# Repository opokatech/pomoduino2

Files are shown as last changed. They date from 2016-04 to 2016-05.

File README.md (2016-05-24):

# Pomoduino2

This project is a simple [pomodoro] hardware timer using [arduino] uno with 16x2
lcd display, 2 buttons and a buzzer.

It keeps track of finished pomodoros (saves them to non-volatile memory) and
counts them up. The logic is described below.

A prototype with Arduino looks like this:

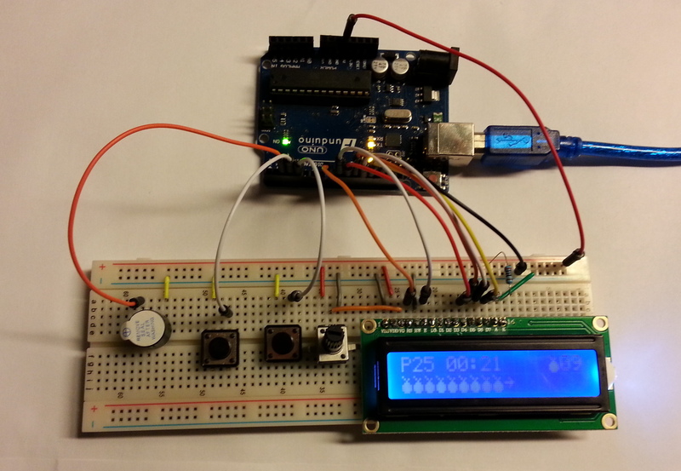
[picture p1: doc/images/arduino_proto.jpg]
pomoduino2 arduino proto Pomoduino2 prototype with arduino
.

... and using nano - like this:

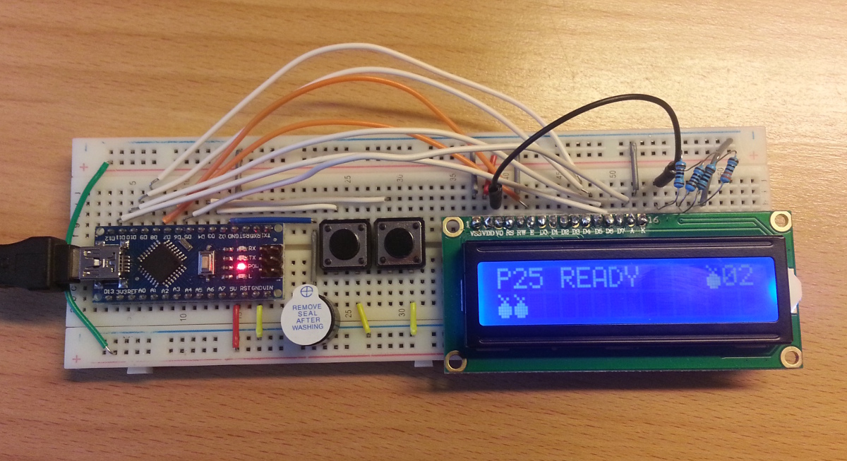
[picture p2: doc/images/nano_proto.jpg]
pomoduino2 nano proto Pomoduino2 prototype with nano
.

# Logic - description

There are 3 timers:
- 25 minutes (aka pomodoro),
- 5 minutes (aka short break),
- 15 minutes (aka long break)

Pressing (and releasing) button 1 (B1) cycles through them.

Pressing (and releasing) button 2 (B2) starts a timer.

When timer elapses it goes automatically to a next one, as described in
[pomodoro] method, i.e. 25 - 5 - 25 - 5 - 25 - 5 - 25 - 15 - 25 - 5 ...

Number of finished pomodoros is visible in the top right corner and also
visualized as a progress bar in the bottom line.

Pressing B2 while running pauses the state. Pressing (and releasing) again makes
it continue.

Holding B2 longer (3s) during pause cancels the timer - it goes back to `ready`
state.

Holding B2 longer (3s) in ready state clears the number of pomodoros done so
far.

The pomodoros are stored in eeprom and thus survive power off.

On a diagram it looks like so:

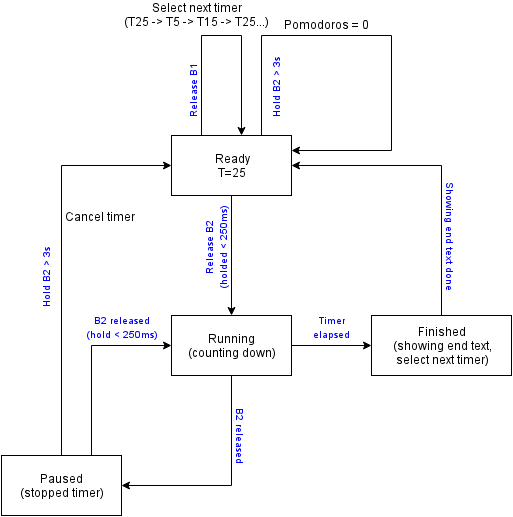
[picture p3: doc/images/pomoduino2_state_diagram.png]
state diagram of pomoduino2 timer State diagram
.

The drawing was made with [draw.io](https://www.draw.io/).

# Schematic

The components were connected as depicted below:

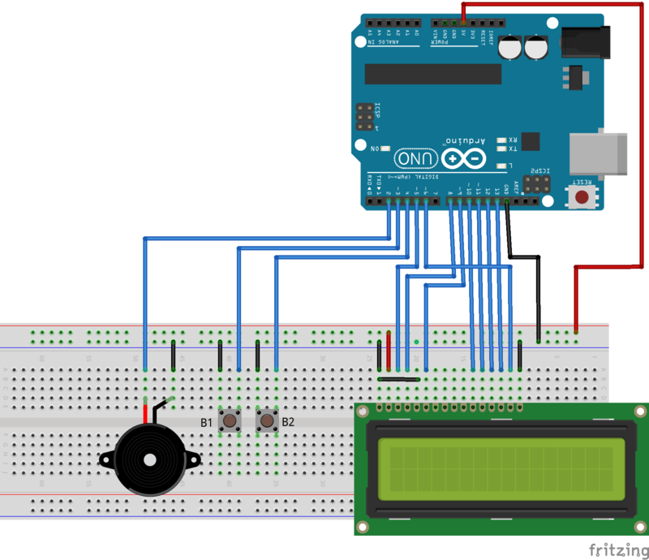
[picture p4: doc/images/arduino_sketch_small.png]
sketch of pomoduino2 timer Sketch diagram
.

# Building

## Hardware

- [arduino] - I used uno and nano328 but should work with others too. As you can
  see it just uses input from 2 buttons and several outputs (LCD, buzzer) so it
  could be adapted to any device having digital I/Os
- 16x2 LCD display - although the software is made so that the UI class, which
  now uses LCD, can be easily replaced by literally anything. As an example
  there is src-alternative/ui/serial/UI, which spits out something on Serial
  console depending on current state. Yet another example (included) is a
  variant using 5 LEDs as "user interface".
- 10k potentiometer (optional) - for controlling contrast. If you don't want
  that just use some resistor placed between V0 pin of the LCD and ground. For
  me 3.3k Ohm worked well, however using a capacitor (100uF) as you can see here:
  [here](/doc/images/nano_sketch_big.png) worked best (forming simple RC
  filter with D5 as PWM).

- 2 buttons
- buzzer - although, again, it can be replaced by any device controller by
  digital output, for example a LED.

## Software

### Quickstart

I'm using [debian] so I could do just this:
```sh
$ apt-get install arduino arduino-mk cmake g++
```

Then in the directory where this repository was cloned:
```sh
$ make lcd # to build a ready to use version
$ make upload # to upload compiled binary to the arduino
```

If you want to play a bit with it there are few more commands, like:

```sh
$ git submodules update --init # to fetch google tests/mock
$ make test # to compile and run tests

$ make lcd-debug # to build a debug version (see below)
$ make serial-debug # to build a debug version with UI_Serial instead of UI_Full
```

### Some explanations

To compile I used arduino-mk. I really recommend that as an alternative to the
official IDE - especially if you would like to:
- use your favourite text editor,
- be able to easily adjust compile options
- make automated builds and testing.

That code is very likely to work using the standard [arduino] IDE, provided that
the files are put in right directories. But I neither tested that nor plan to.

The `debug` target adds some extra debug messages which are spit out on serial
interface (with `picocom /dev/ttyUSB0` you can watch it) AND it changes times of pomodoro
periods from minutes to seconds which is very useful for testing.

For testing the code I used [google test] which also includes google mock. I
used both as submodules (they are in `/modules` directory). It matters of
course only if you need/want to run tests.

# License

[MIT](LICENSE)

----
Documentation was tested using [dillinger.io](http://dillinger.io/).

[//]: # (These are reference links used in the body of this note and get stripped out when the markdown processor does its job. There is no need to format nicely because it shouldn't be seen. Thanks SO - http://stackoverflow.com/questions/4823468/store-comments-in-markdown-syntax)

[arduino]: <https://www.arduino.cc/>
[debian]: <https://www.debian.org/>
[googletest]: <https://github.com/google/googletest>
[pomodoro]: <https://en.wikipedia.org/wiki/Pomodoro_Technique>

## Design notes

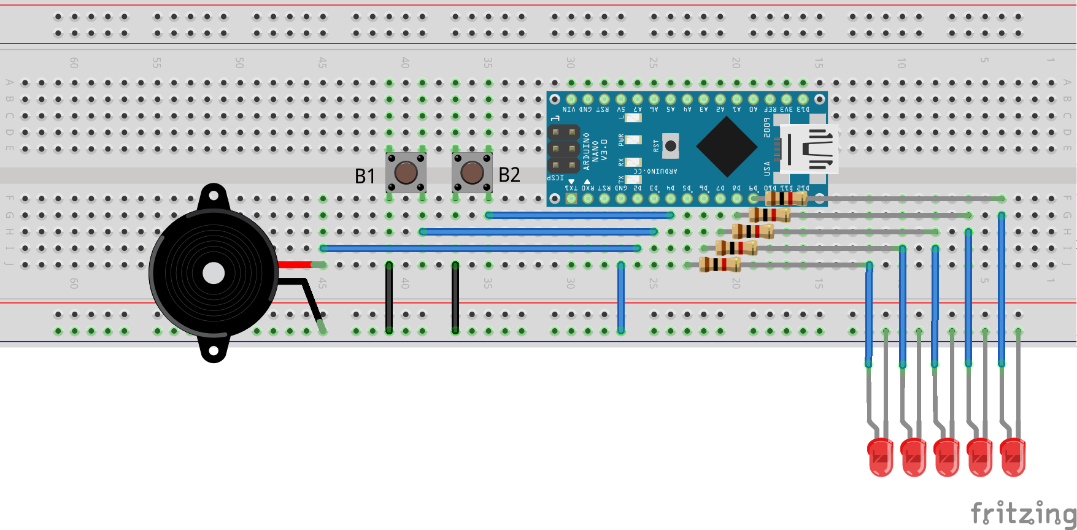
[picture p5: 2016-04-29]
doc/images/nano_leds_sketch_big.png

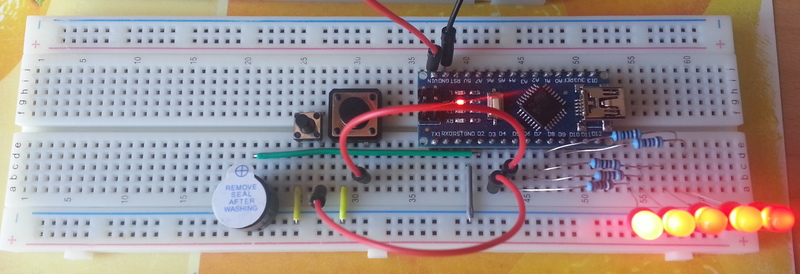
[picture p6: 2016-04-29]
doc/images/nano_leds_proto.jpg

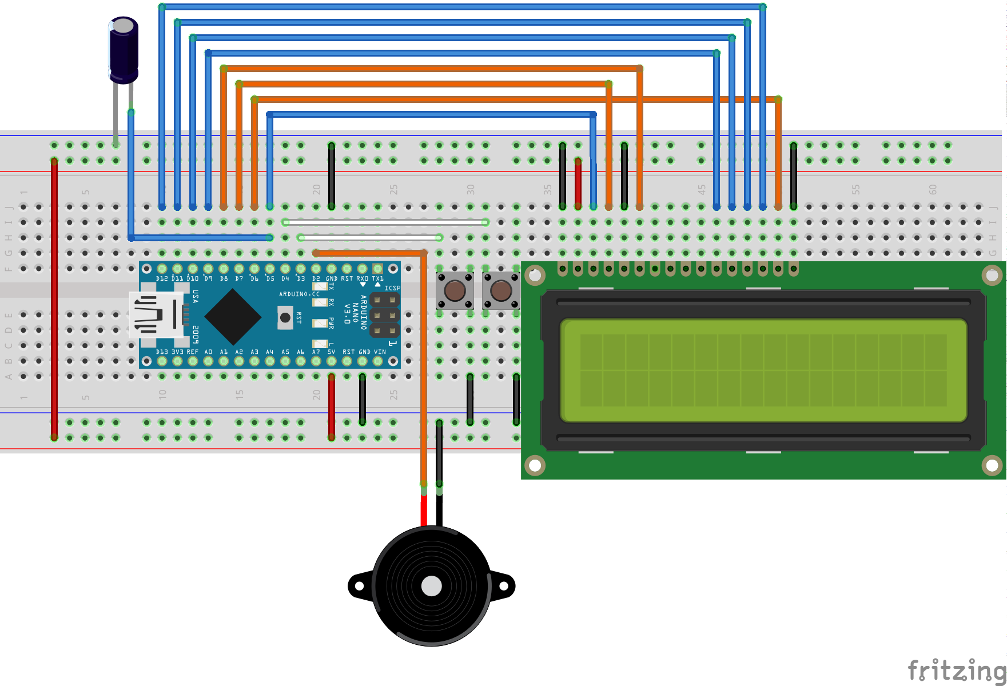
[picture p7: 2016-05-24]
doc/images/nano_sketch_big.png

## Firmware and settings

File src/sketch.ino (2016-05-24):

/*
Copyright (c) 2016 Miroslaw Opoka <mirek@opoki.com>

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
THE SOFTWARE IS PROVIDED "AS IS", WITHOUT WARRANTY OF ANY KIND, EXPRESS OR
IMPLIED, INCLUDING BUT NOT LIMITED TO THE WARRANTIES OF MERCHANTABILITY,
FITNESS FOR A PARTICULAR PURPOSE AND NONINFRINGEMENT. IN NO EVENT SHALL THE
AUTHORS OR COPYRIGHT HOLDERS BE LIABLE FOR ANY CLAIM, DAMAGES OR OTHER
LIABILITY, WHETHER IN AN ACTION OF CONTRACT, TORT OR OTHERWISE, ARISING FROM,
OUT OF OR IN CONNECTION WITH THE SOFTWARE OR THE USE OR OTHER DEALINGS IN THE
SOFTWARE.
*/

#include "Const.hpp"
#include "Pomodoro.hpp"
#include "Button.hpp"
#include "Eeprom.hpp"
#include "UI.hpp"

MO::Button the_b1(MO::Const::PIN_B1);
MO::Button the_b2(MO::Const::PIN_B2);
MO::Eeprom the_eeprom;
MO::UI     the_ui;

// for MO::Pomodoro it does not matter what UI it uses
MO::Pomodoro the_pomodoro(&the_ui, &the_b1, &the_b2, &the_eeprom);
uint32_t the_time = 0;

#ifdef MO_DEBUG
uint8_t the_contrast = 128;
uint8_t the_brightness = 128;
#endif

void setup()
{
    the_b1.Setup();
    the_b2.Setup();
    the_pomodoro.Setup();
#ifdef MO_DEBUG
    Serial.begin(9600);
#endif
}

void loop()
{
    the_time = millis();

    the_b1.Update(the_time);
    the_b2.Update(the_time);
    the_pomodoro.Run(the_time);

#ifdef MO_DEBUG
    // for adjusting contrast and brightness
    if (Serial.available() > 0)
    {
        int b = Serial.read();

        if (b == 'c')
        {
            the_contrast += 8;
            analogWrite(MO::Const::PIN_LCD_CONTRAST, the_contrast);
            Serial.print("contrast: ");
            Serial.println(the_contrast, DEC);
        }
        else if (b == 'b')
        {
            the_brightness += 8;
            analogWrite(MO::Const::PIN_LCD_BRIGHTNESS, the_brightness);
            Serial.print("brightness: ");
            Serial.println(the_brightness, DEC);
        }
    }
#endif

    delay(100);
}

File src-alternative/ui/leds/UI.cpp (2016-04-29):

/*
Copyright (c) 2016 Miroslaw Opoka <mirek@opoki.com>

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
THE SOFTWARE IS PROVIDED "AS IS", WITHOUT WARRANTY OF ANY KIND, EXPRESS OR
IMPLIED, INCLUDING BUT NOT LIMITED TO THE WARRANTIES OF MERCHANTABILITY,
FITNESS FOR A PARTICULAR PURPOSE AND NONINFRINGEMENT. IN NO EVENT SHALL THE
AUTHORS OR COPYRIGHT HOLDERS BE LIABLE FOR ANY CLAIM, DAMAGES OR OTHER
LIABILITY, WHETHER IN AN ACTION OF CONTRACT, TORT OR OTHERWISE, ARISING FROM,
OUT OF OR IN CONNECTION WITH THE SOFTWARE OR THE USE OR OTHER DEALINGS IN THE
SOFTWARE.
*/

#include <Arduino.h>

#include "UI.hpp"
#include "Utils.hpp"
#include "Const.hpp"

namespace MO
{
    UI::UI(): the_timer(0), the_beeper(Const::PIN_BEEPER, 1)
    {
        Utils::debug("UI leds started\n");
    }

    // -------------------------------------------------------------------------

    void UI::Show_Ready(const State_IF &a_state)
    {
        // in ready state indicated what is next, pause for some time
        // and show how many are done TODO
        the_timer += 1;

        if (the_timer >= 10)
        {
            the_timer = 0;
        }

        if (the_timer < 5)
        {
            show_pom_period(a_state);
        }
        else
        {
            show_done_pom(a_state);
        }

    }

    // -------------------------------------------------------------------------

    void UI::Show_Running(const State_IF &a_state)
    {
        uint32_t time_pct = a_state.Get_Time_Left_Ms() * 100/
                            a_state.Get_Time_Max_Ms();

        digitalWrite(PIN_L1, (time_pct > 0) ? HIGH: LOW);
        digitalWrite(PIN_L2, (time_pct > 20)? HIGH: LOW);
        digitalWrite(PIN_L3, (time_pct > 40)? HIGH: LOW);
        digitalWrite(PIN_L4, (time_pct > 60)? HIGH: LOW);
        digitalWrite(PIN_L5, (time_pct > 80)? HIGH: LOW);
    }

    // -------------------------------------------------------------------------

    void UI::Show_Paused(const State_IF &a_state)
    {
        the_timer += 1;

        if (the_timer >= 10)
        {
            the_timer = 0;
        }

        if (the_timer < 5)
        {
            show_pom_period(a_state);
        }
        else
        {
            show_all_dark();
        }
    }

    // -------------------------------------------------------------------------

    void UI::Show_Finished(const State_IF &a_state)
    {
        if (the_timer % 2)
        {
            show_pom_period(a_state);
        }
        else
        {
            show_all_dark();
        }

        if (the_timer > 0)
            the_timer -= 1;
        the_beeper.Update();
    }

    // -------------------------------------------------------------------------

    void UI::Set_Beeper(byte a_val)
    {
        the_timer = a_val * 10;
        the_beeper.Reset(a_val);
    }

    // -------------------------------------------------------------------------

    bool UI::Showing() const
    {
        return (the_timer != 0) || (the_beeper.Done() == false);
    }

    // -------------------------------------------------------------------------

    void UI::Setup()
    {
        pinMode(PIN_L1, OUTPUT);
        pinMode(PIN_L2, OUTPUT);
        pinMode(PIN_L3, OUTPUT);
        pinMode(PIN_L4, OUTPUT);
        pinMode(PIN_L5, OUTPUT);

        the_beeper.Setup();
    }

    // -------------------------------------------------------------------------

    void UI::show_all_dark()
    {
        digitalWrite(PIN_L1, LOW);
        digitalWrite(PIN_L2, LOW);
        digitalWrite(PIN_L3, LOW);
        digitalWrite(PIN_L4, LOW);
        digitalWrite(PIN_L5, LOW);
    }

    // -------------------------------------------------------------------------

    void UI::show_pom_period(const State_IF &a_state)
    {
        uint8_t period_min = a_state.Get_Current_Period_Minutes();
        if (period_min == Const::POM_WORK_MIN)
        {
            digitalWrite(PIN_L1, HIGH);
            digitalWrite(PIN_L2, HIGH);
            digitalWrite(PIN_L3, HIGH);
            digitalWrite(PIN_L4, HIGH);
            digitalWrite(PIN_L5, HIGH);
        }
        else if (period_min == Const::POM_BREAK_SHORT_MIN)
        {
            digitalWrite(PIN_L1, HIGH);
            digitalWrite(PIN_L2, LOW);
            digitalWrite(PIN_L3, LOW);
            digitalWrite(PIN_L4, LOW);
            digitalWrite(PIN_L5, LOW);
        }
        else if (period_min == Const::POM_BREAK_LONG_MIN)
        {
            digitalWrite(PIN_L1, HIGH);
            digitalWrite(PIN_L2, HIGH);
            digitalWrite(PIN_L3, HIGH);
            digitalWrite(PIN_L4, LOW);
            digitalWrite(PIN_L5, LOW);
        }
    }

    // -------------------------------------------------------------------------

    void UI::show_done_pom(const State_IF &a_state)
    {
        uint8_t pom = a_state.Get_Pomodoros();

        digitalWrite(PIN_L1, (pom & B10000) ? HIGH: LOW);
        digitalWrite(PIN_L2, (pom & B1000)  ? HIGH: LOW);
        digitalWrite(PIN_L3, (pom & B100)   ? HIGH: LOW);
        digitalWrite(PIN_L4, (pom & B10)    ? HIGH: LOW);
        digitalWrite(PIN_L5, (pom & B1)     ? HIGH: LOW);

    }
}

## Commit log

2016-04-14 initial commit of the code
    [pomoduino2_sketch.fzz]
2016-04-23 changed wiring to easier to connect
    [pomoduino2_sketch.fzz]
2016-04-23 added prototype photo
2016-04-23 updated sketch
    now connections are as in the code
    [pomoduino2_sketch.fzz]
2016-04-28 simplified UI builds
    To avoid compilation all UI_* into a firmware, now the variants are in
    src-alternative and are linked into src/ui/ by makescript.
    [UI.cpp, UI.hpp, sketch.ino]
2016-04-29 leds ui
2016-04-29 makefile ordered targets
    lcd - standard lcd ui
    lcd-debug - as above for testing (shorted times + debug)
    serial-debug - serial ui
    leds - standard leds ui
    leds-debug - as above for testing
2016-04-29 ui - leds - shows number of done pomodoros
    in ready state it shows alternating done pomodoros/current period.
    done pomodoros encoded binary
2016-04-29 added images and sketch of "only-leds" variant
    [pomoduino2_only_leds.fzz]
2016-05-02 LCD brithness and contrast with PWM pins
2016-05-02 updated sketch
    [pomoduino2_sketch.fzz]
2016-05-02 pomoduino2 on nano + brightness pwm
    [arduino.fzz, nano.fzz, nano_only_leds.fzz]
2016-05-24 using RC filter instead of resistors for LCD contrast
    [nano.fzz]
2016-05-24 using arduino-mk for building
